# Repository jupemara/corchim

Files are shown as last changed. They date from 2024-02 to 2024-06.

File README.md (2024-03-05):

# corchim

Corchim ([Corne](https://github.com/foostan/crkbd/tree/main) by [foostan@](https://twitter.com/foostan) alminum gasket mount case) build guide

## 日本語はこちら

- Corne cherry v3
  - [PCB](./docs/ja/corne-cherry-v3.md)
  - [Corchim](./docs/ja/corchim-cherry-v3.md)

## English version

- Corne cherry v3
  - [PCB](./docs/en/corne-cherry-v3.md)
  - [Corchim](./docs/en/corchim-cherry-v3.md)

## switch plate data (.step and .dxf)

under the `data/switch-plate` dir

- corchim-switch-plate-{left,right}.{step,dxf}
  - normal corchim switch plate. If you need other material switch plates, please use those data.
- corchim-switch-plate-topre-{left,right}.{step,dxf}
  - for topre housing, 14.6 x 14
  - maybe for CorneECRevival, however I have not try strictly... TRRS connector position seems to be slightly changed compared with original corne v3.
- corchim-switch-plate-xiao-{left,right}.{step,dxf}
  - for xiao/rev2
  - maybe you can put batteries under the OLED. however nice!view is sold out in everywhere :innocent::innocent::innocent:

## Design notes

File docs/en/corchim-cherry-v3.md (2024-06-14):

# Corchim with Corne Cherry v3

## Procedures

### 1. Check the Contents

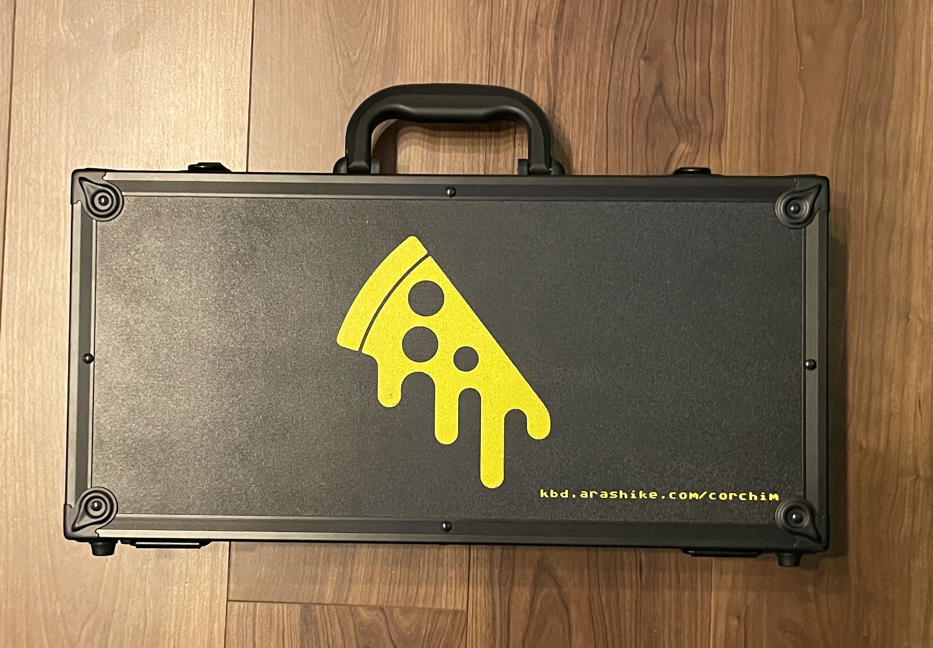
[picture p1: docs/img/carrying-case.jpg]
Open the carrying case


| Name | Quantity |
| --- | --- |
| Complete set for both left and right cases | 1 pair |
| Case foam (to be placed between the case and the PCB) | 2 pairs  |
| Switch foam (to be placed between the PCB and switch plate) | 1 pair |
| Switch plate (Polycarbonate) | 1 pair |
| Gasket (with adhesive) | 1 pair |
| Height adjustment foam for MCU | 1 pair |
| OLED pin socket with 5.7mm height | 2 pieces |
| OLED pin header with 1.5mm height | 2 pieces |
| Rubber Feet | 8 pieces |

Only BoB, different screws is used from the factory assembly, so screws are included separately.
Space Gray uses factory assembled screws.

| Name | Quantity |
| --- | --- |
| Screws for securing top and bottom of the case: Hex M2 x 8mm | 8 pieces (4 each for left and right) |
| Screws for securing weight: Hexalobular M3 x 4mm | 4 pieces (2 each for left and right) |

Each left and right case includes:

- left
  - Top body
  - Bottom body
  - Weight
  - PC plate
- right
  - Top body
  - Bottom body
  - Weight
  - PC plate

### 2. Remove the Case and Unscrew

Unscrew the temporarily fixed screws from the factory.

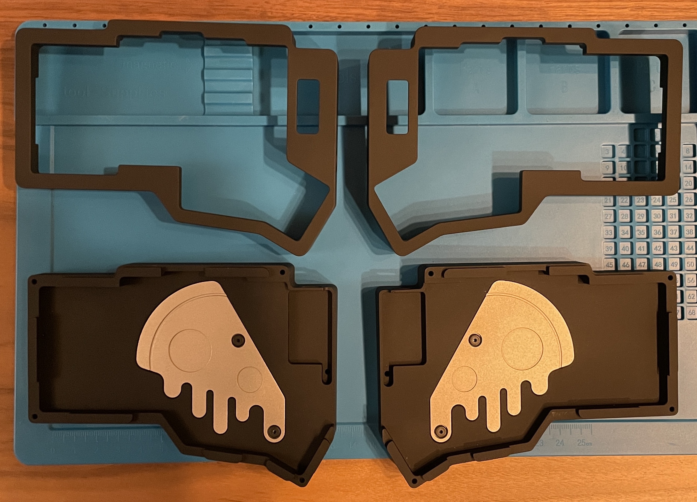
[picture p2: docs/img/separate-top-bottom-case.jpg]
Separating the case


#### Only BoB

Replace the weight screws with the provided black M3 x 4mm screws.
Space Gray is used as is from the factory, so there is no need to unscrew the weights.

#### Wrench

- For Space Gray
  - Hex wrench 1.27mm (0.05 inch)
- For BoB
  - removal: Hex wrench 1.5mm
  - installation: Hex wrench 1.25mm (0.05 inch) + T8 torx screwdriver (for weight)

### 3. Installing the Case Foam

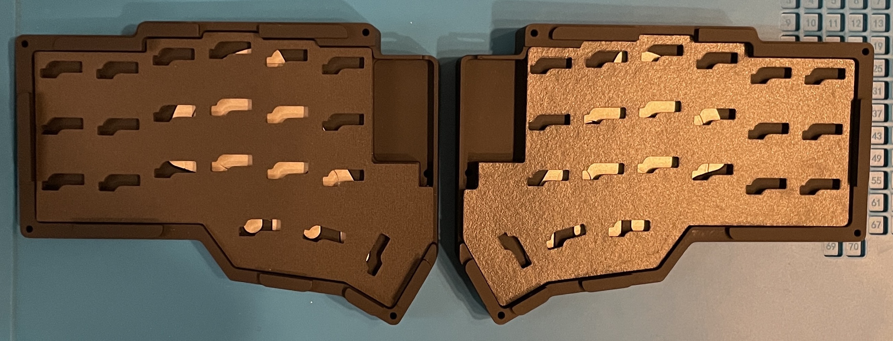
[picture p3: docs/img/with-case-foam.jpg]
Installing the case foam


#### 3-a. (optional) Installing the MCU Foam

While not necessary, this mitigates the mcu shifting around when unplugging and plugging in the USB-C port.
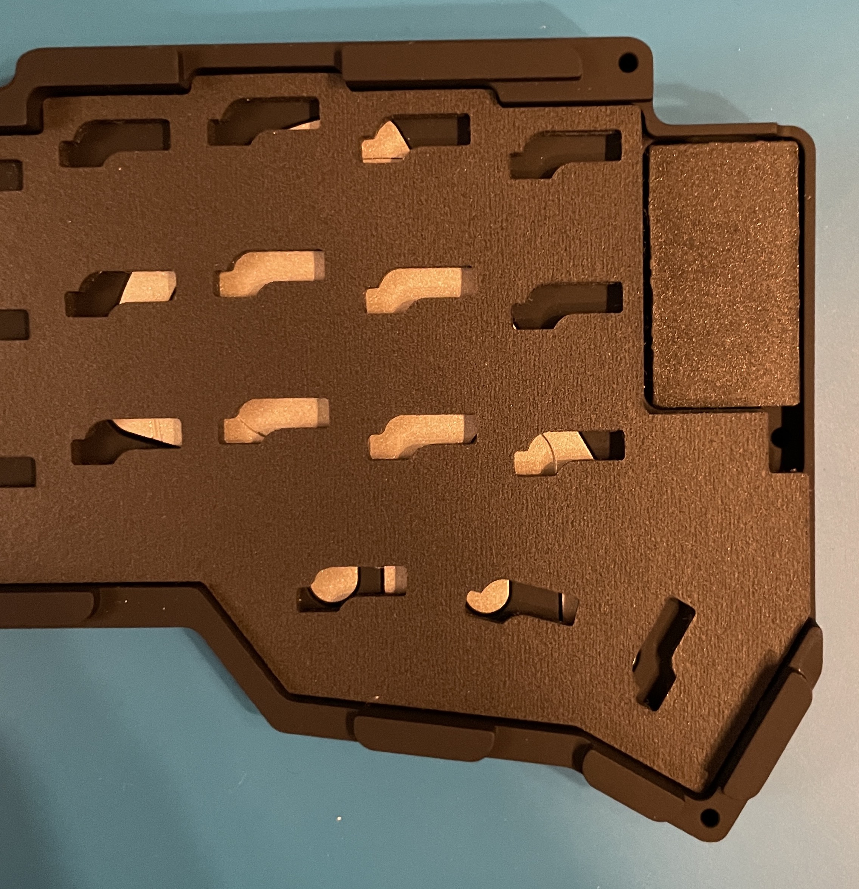
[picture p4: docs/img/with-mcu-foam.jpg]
with MCU foam


#### 3-b. (optional) When Installing a PCB with LEDs

If you already have LEDs installed, it's a single layer of case foam, otherwise the board will feel stiff.

### 4. Installing the PCB

Place the PCB on top of the case foam, ensuring it aligns with the socket holes in the foam.

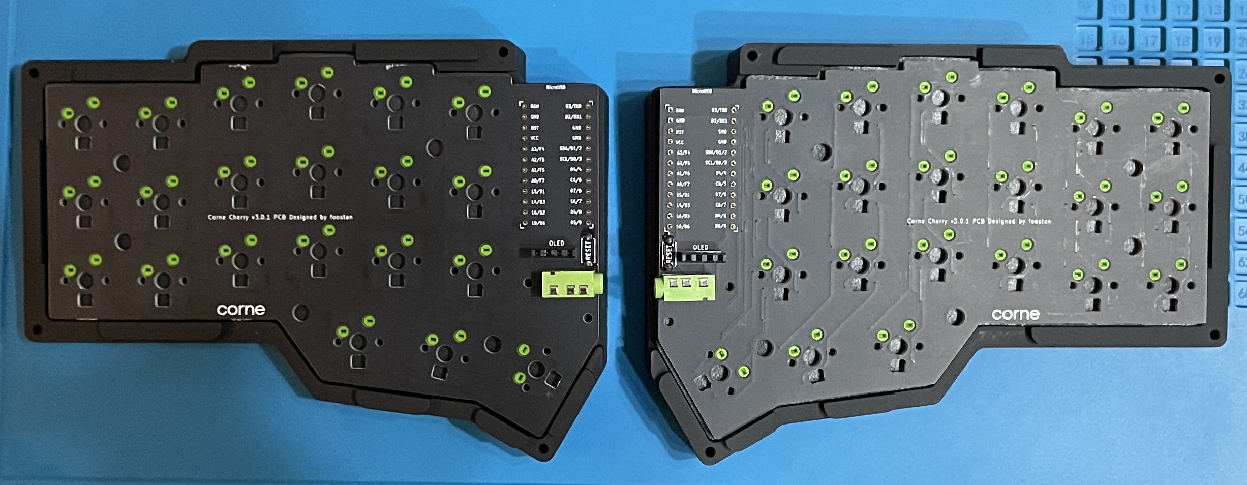
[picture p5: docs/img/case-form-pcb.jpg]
Installing the PCB


### 5. Gasket and OLED Supporting Foam

Attach the gasket to the switch plate.

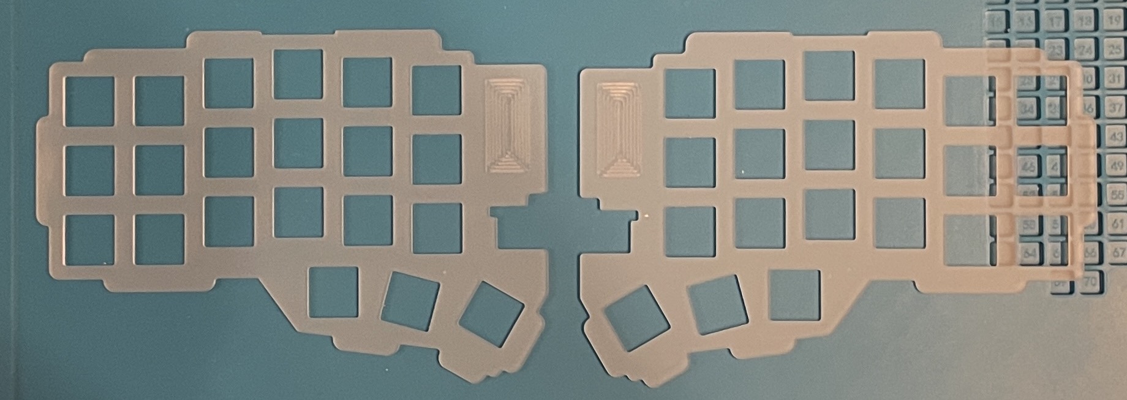
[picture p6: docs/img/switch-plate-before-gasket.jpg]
Switch plate before attaching gasket


At this time, also attach the OLED supporting foam to fit the OLED recess.

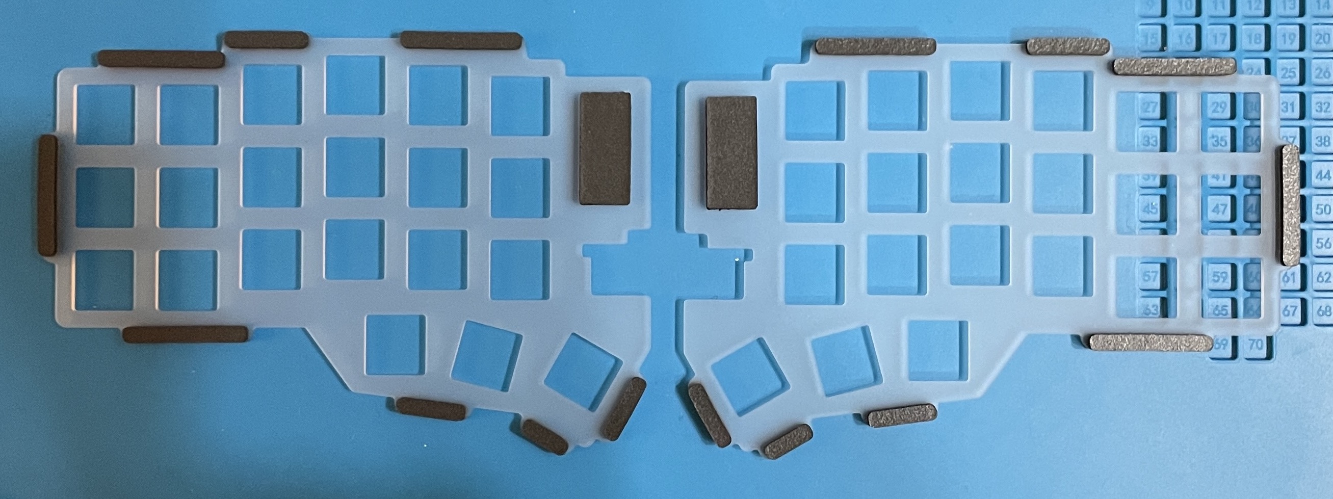
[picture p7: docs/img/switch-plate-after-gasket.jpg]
Switch plate after attaching gasket


The gasket comes in four lengths, so attach them to fit both sides (front and back).

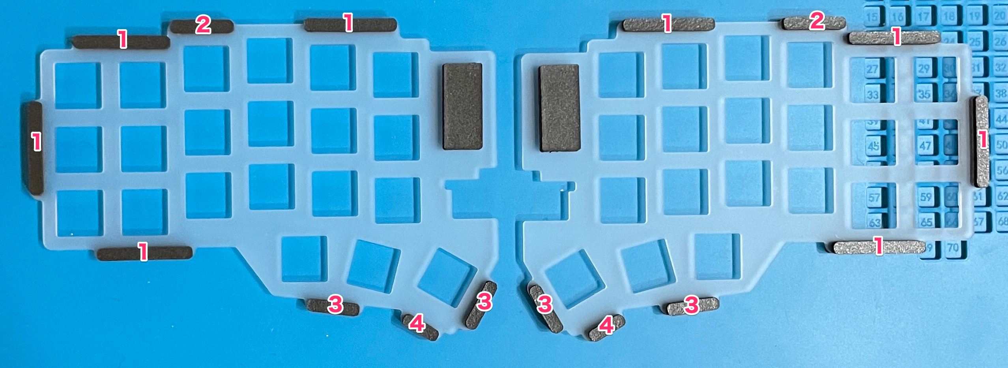
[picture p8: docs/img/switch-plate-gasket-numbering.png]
Numbering of gaskets on the switch foam side


### 6. Setting the Switch Plate and Switch Foam

Lay the switch foam on top of the PCB as shown in the picture.

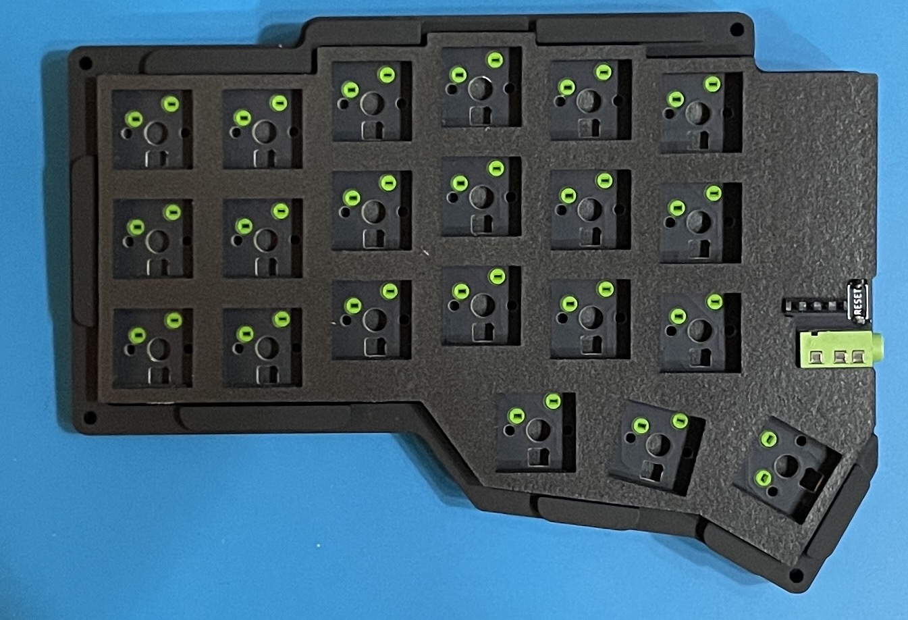
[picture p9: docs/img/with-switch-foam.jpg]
Laying the switch foam


Then, lay the switch plate on top. To prevent the switch plate and switch foam from shifting when covering the case, secure the four corners with appropriate key switches.
This is also a good time to add the OLED.

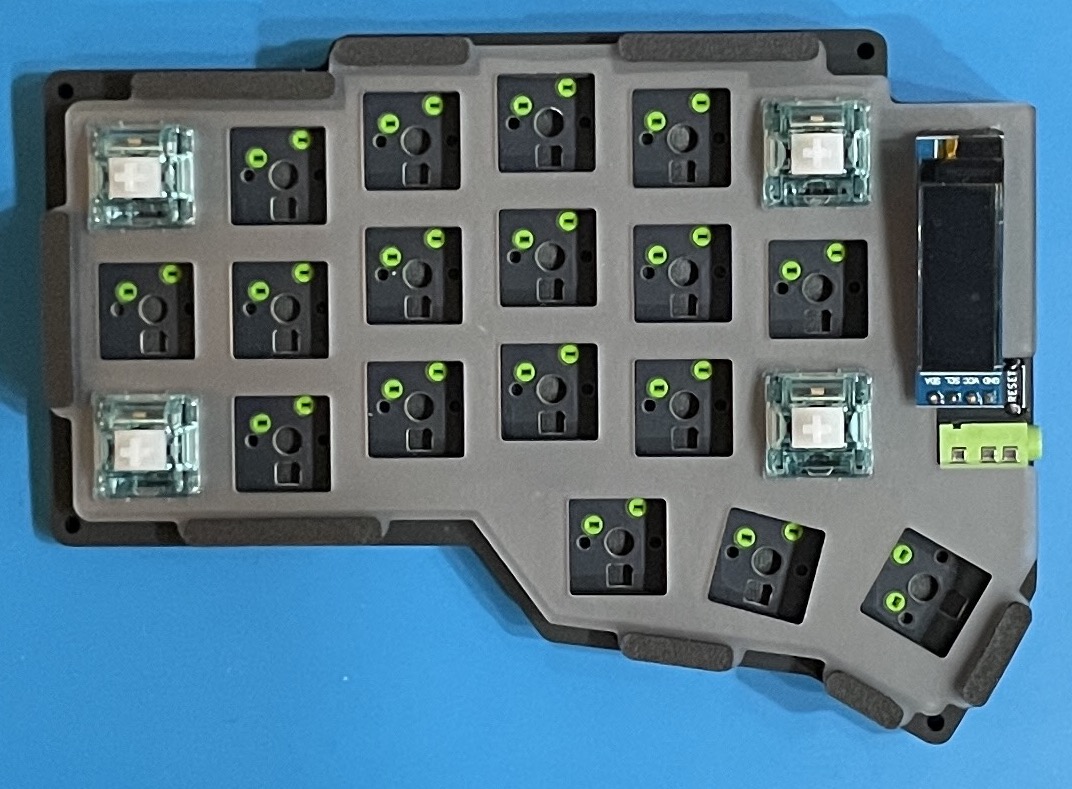
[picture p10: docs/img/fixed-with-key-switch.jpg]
Securing the foam and switch plate with key switches


### 7. Cover with Top Body and Screw Together

Cover with the top body and secure from the bottom with four M2 x 8mm screws.

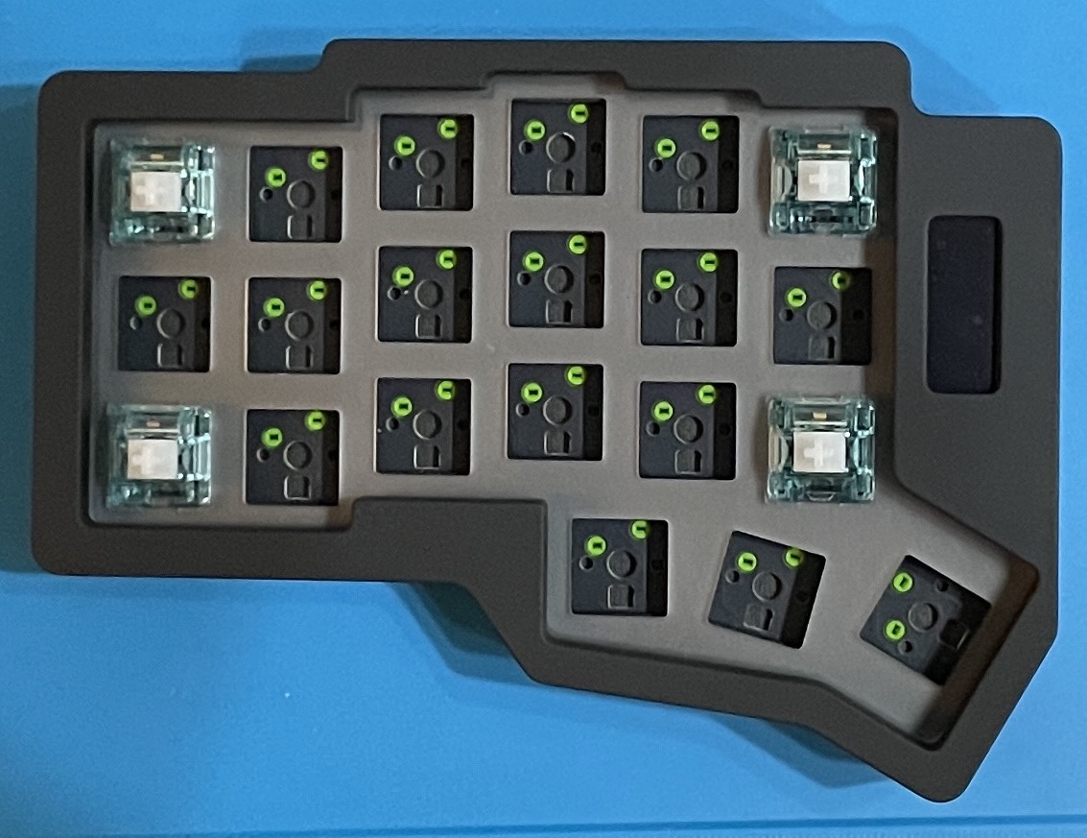
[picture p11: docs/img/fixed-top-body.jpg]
Securing the top and bottom


### 8. Rubber Feet

Attach the rubber feet to the holes on the bottom of the case.

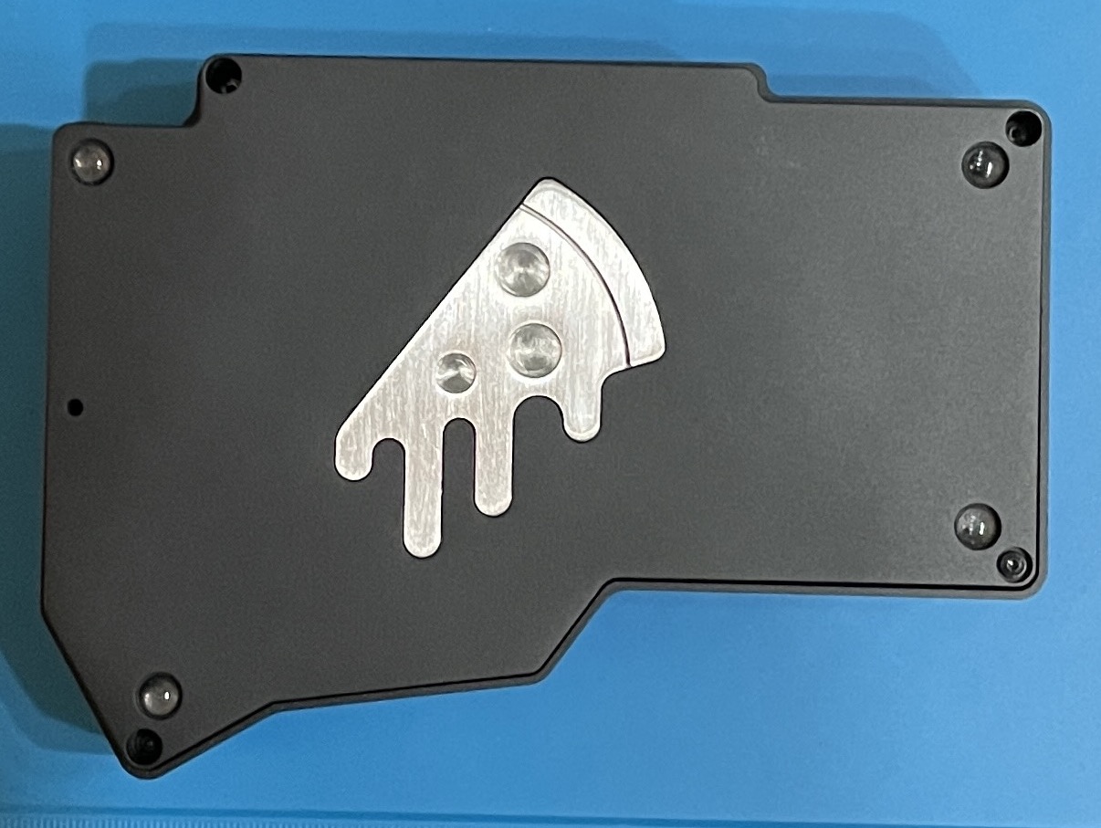
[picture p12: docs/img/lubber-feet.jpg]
Attaching rubber feet


### 9. Keycaps

Attach the keycaps, and it's complete!! Congrats!! Enjoy your Corchim!!

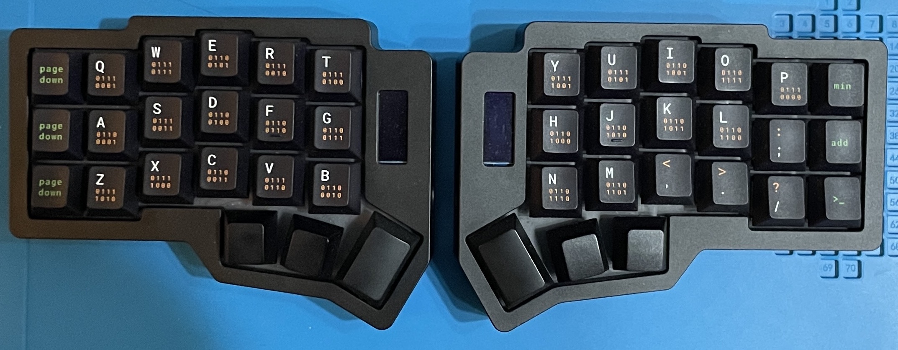
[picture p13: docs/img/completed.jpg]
Completed!!


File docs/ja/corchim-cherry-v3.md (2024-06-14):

# Corchim /w corne cherry v3

## 手順

### 1. 同梱物の確認

キャリングケースを開ける

| 名称 | 個数 |
| --- | ---- |
| ケース左右一式 | 1 対 |
| ケースフォーム (ケースと PCB の間に挟むもの) | 2 対 |
| スイッチフォーム (PCB とスイッチプレートの間に挟むもの) | 1 対 |
| スイッチプレート (ポリカーボネート) | 1 対 |
| ガスケット (粘着付き) | 1 対 |
| MCU 用高さ調整フォーム | 1 対 |
| OLED 高さ 5.7mm ピンソケット | 2 個 |
| OLED 高さ 1.5mm ピンヘッダ | 2 個 |
| ゴム足 | 8 個 |

BoB のみ工場組立とは異なるネジを使用するため、別途ネジが同梱されます。
Space Gray は工場組立のネジをそのまま利用します。

| 名称 | 個数 |
| --- | --- |
| ケース上下締結用ネジ: 六角 M2 x 8mm | 8 本 (左右 4 本ずつ) |
| ウェイト締結用ネジ: ヘクサロビュラ M3 x 4mm | 4 本 (左右 2 本ずつ) |

ケース左右には以下が含まれます

- left
  - トップ側ボディ
  - ボトム側ボディ
  - ウェイト
  - スイッチプレート
- right
  - トップ側ボディ
  - ボトム側ボディ
  - ウェイト
  - スイッチプレート

### 2. ケースを取り出し、ネジをはずす

工場製造時に仮止めしてあるネジがついているのでそちらのネジを外します。

ケースの分割

#### BoB のみ

ウェイトのネジを仮止め用のネジから付属の黒いネジ M3 x 4mm ネジと交換します。
Space Gray は工場組立時のそのまま利用するので、ウェイトのネジを外す必要はありません。

#### 使用するレンチ

- Space Gray
  - 六角レンチ 1.27mm (0.05 インチ)
- BoB
  - 取り外し: 六角レンチ 1.5mm
  - 取り付け: 六角レンチ 1.27mm (0.05 inch) + T8 トルクスドライバー (ウェイト用)

### 3. ケースフォームの設置

ケースフォームの設置

#### 3-a. (optional) MCU フォームの設置

通常必要ないはずですが、USB の抜き差しによって MCU が外れやすい場合は、こちらのフォームを敷いてください。
with MCU foam

#### 3-b. (optional) LED を実装した PCB を設置する際

アンダーグロー LED を実装済みの PCB を使用する際は、ケースフォームを 1 枚分の厚みだけで利用することを推奨します。
(2 枚の厚みでも問題なく動作しますが、ちょっと中身つまり過ぎな気がします)

### 4. PCB の設置

ケースフォームの上に PCB を設置します。このときケースフォームのソケットの位置に PCB が合うように設置します。

PCBの設置

### 5. ガスケットと OLED を支えるフォーム

スイッチプレートにガスケットを貼ります。

ガスケットを貼る前のスイッチプレート

このとき、OLED 用のくぼみに合うように OLED 用フォームも貼ります。

ガスケットを貼った後のスイッチプレート

ガスケットには長さが 4 種類あるのでサイズが合うように表面/裏面の両方に貼ります。

スイッチフォーム側のガスケットのナンバリング

### 6. スイッチプレートとスイッチフォームの設定

写真のようにスイッチフォームを PCB の上に敷きます。

スイッチフォームを敷く

さらにその上にスイッチプレートを敷きます。ケースを被せるときにスイッチプレートとスイッチフォームがずれるのを防ぐために適当なキースイッチで四隅を固定します。

キースイッチでフォームとスイッチプレートを固定する

### 7. トップボディをかぶせてネジで締結

トップボディをかぶせて、底側から M2 x 8mm のネジ 4 本で締結します。

上下の締結

### 8. ゴム足

ケース底面の穴にゴム足を取り付けます。

ゴム足の取り付け

### 9. キーキャップ

キーキャップを取り付けて完成!! Congrats!! Corchim をお楽しみください!!

完成!!

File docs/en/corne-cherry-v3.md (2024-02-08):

# Preparation for Corne Cherry v3 PCB

## Items Needed for PCB Assembly

| Name | Quantity |
| --- | --- |
| Corne Cherry v3 PCB | 1 set (left and right) |
| Surface mount diodes (1N4148W) | 42 |
| PCB sockets for MX | 42 |
| TRRS jack (PJ-320A) | 2 |
| OLED 128x32 | 2 |
| Compatible MCU | 2 |
| MCU conthrough(spring pin headers) or pin socket (height 2.5mm) | 4 |
| Tactile switches for reset (2 pin) | 2 |

---

The following items are necessary but included with Corchim:

| Name | Quantity |
| --- | --- |
| Pin sockets for OLED | 2 |
| Pin headers for OLED | 2 |

### A Note About the Color of Kailh MX Sockets

Since I was asked about this, the color doesn't matter; it's just fashion (although you might not see it with the case on). Places to purchase include:

- [Daily Craft Shop](https://shop.dailycraft.jp/products/keyswitch_socket_transparent)
- [Chosfox](https://chosfox.com/products/kailh-colorful-hot-swap-socket)
- [AliExpress](https://ja.aliexpress.com/item/1005003174680450.html)

### Compatible MCUs

- Elite-C
- Elite-Pi
- key micro
- Sea-Picro

For the key micro and Sea-Picro, we have confirmed that they operate without soldering on the MCU side. However, using Sea-Picro without soldering is not recommended due to its tendency to detach easily.

### About MCU conthrough

Due to the USB-C port, we recommend a height of 2.5mm.

## Assembly Steps

### 1. Soldering Diodes and Sockets

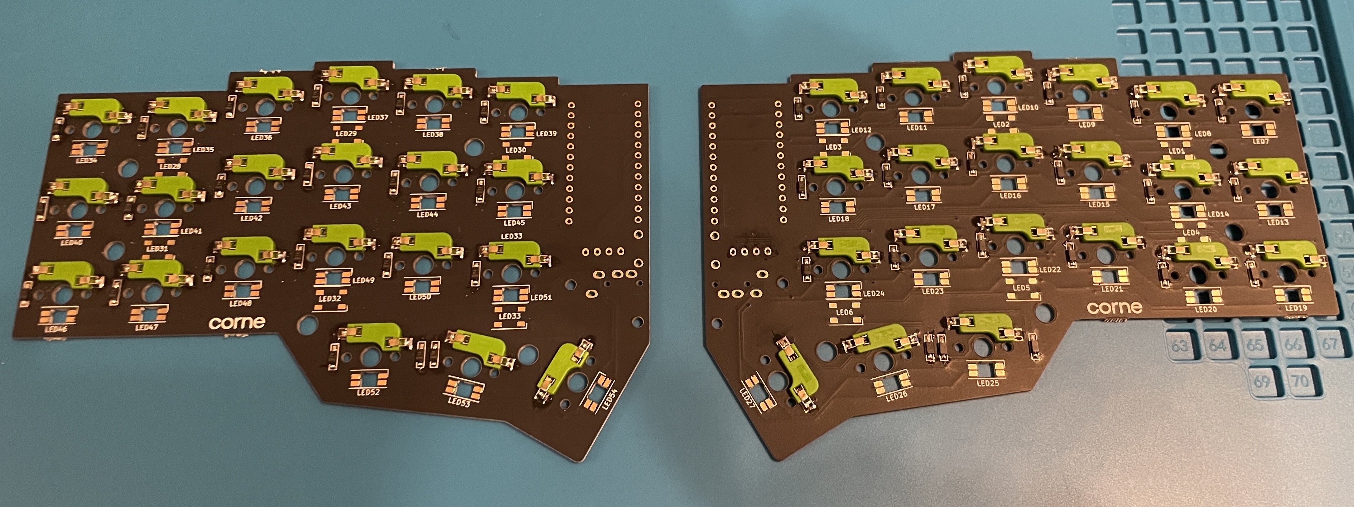
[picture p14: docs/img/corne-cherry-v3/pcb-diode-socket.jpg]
Soldering Diodes and Sockets


The soldering of [diodes](https://github.com/foostan/crkbd/blob/main/corne-cherry/doc/v3/buildguide_en.md#diodes) and [sockets](https://github.com/foostan/crkbd/blob/main/corne-cherry/doc/v3/buildguide_en.md#switch-sockets) follows the same steps as the [original Corne](https://github.com/foostan/crkbd/blob/main/corne-cherry/doc/v3/buildguide_en.md). LEDs are not supported, but having them is not a problem (more on this later).

### 2. Soldering the TRRS

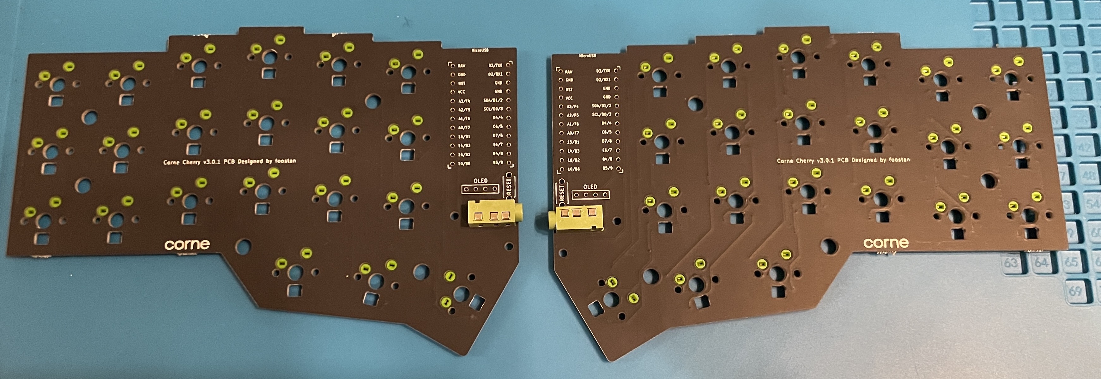
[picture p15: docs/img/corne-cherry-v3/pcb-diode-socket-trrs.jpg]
Soldering the TRRS


The TRRS jack is also soldered following the same procedure as the original Corne.

### 3. Soldering OLED Pin Sockets

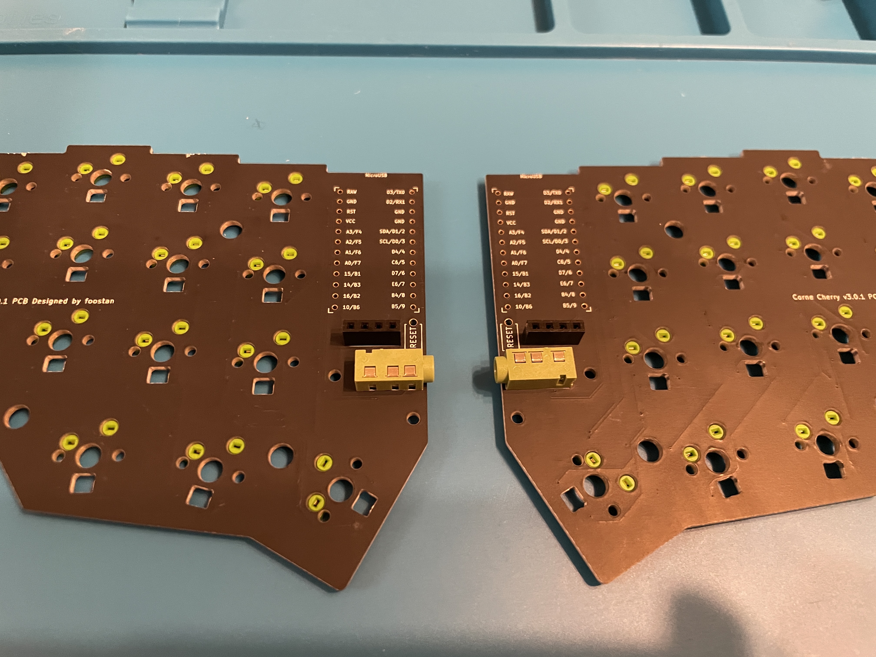
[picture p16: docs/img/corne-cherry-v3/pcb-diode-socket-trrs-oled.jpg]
Soldering OLED 5.7mm Pin Sockets


We include 5.7mm pin sockets and 1.5mm pin headers. However, the original 3.5mm pin sockets are also fine to use. Below are comparison images (there isn't much difference once the case is on).

3.5mm pin socket with 2.5mm pin header

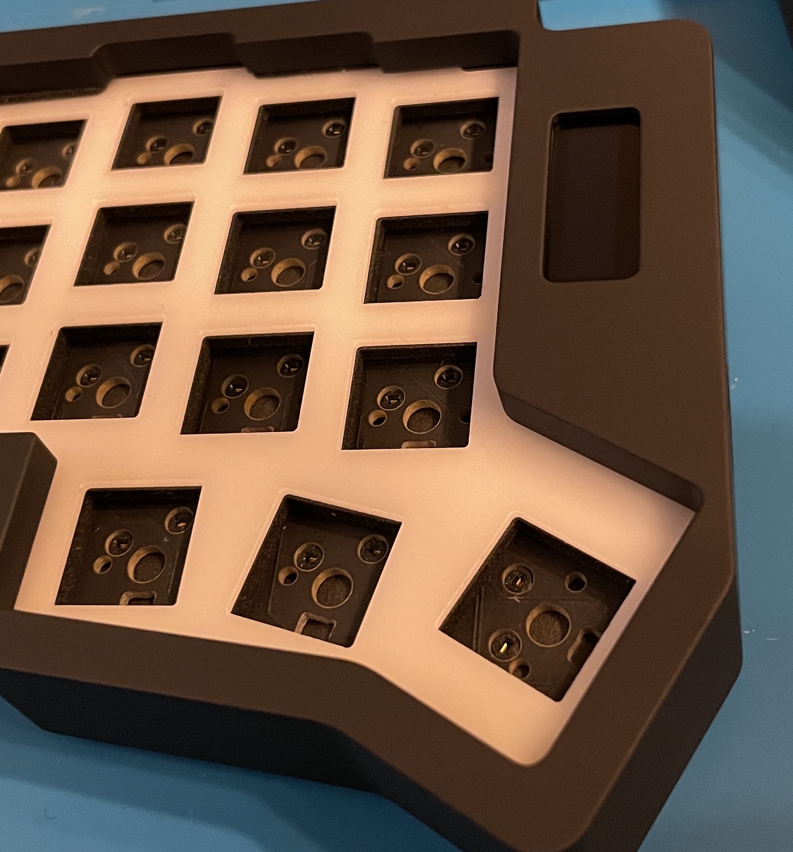
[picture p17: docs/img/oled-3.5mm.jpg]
3.5mm Pin Socket + Corchim


5.7mm pin socket with 1.5mm pin header

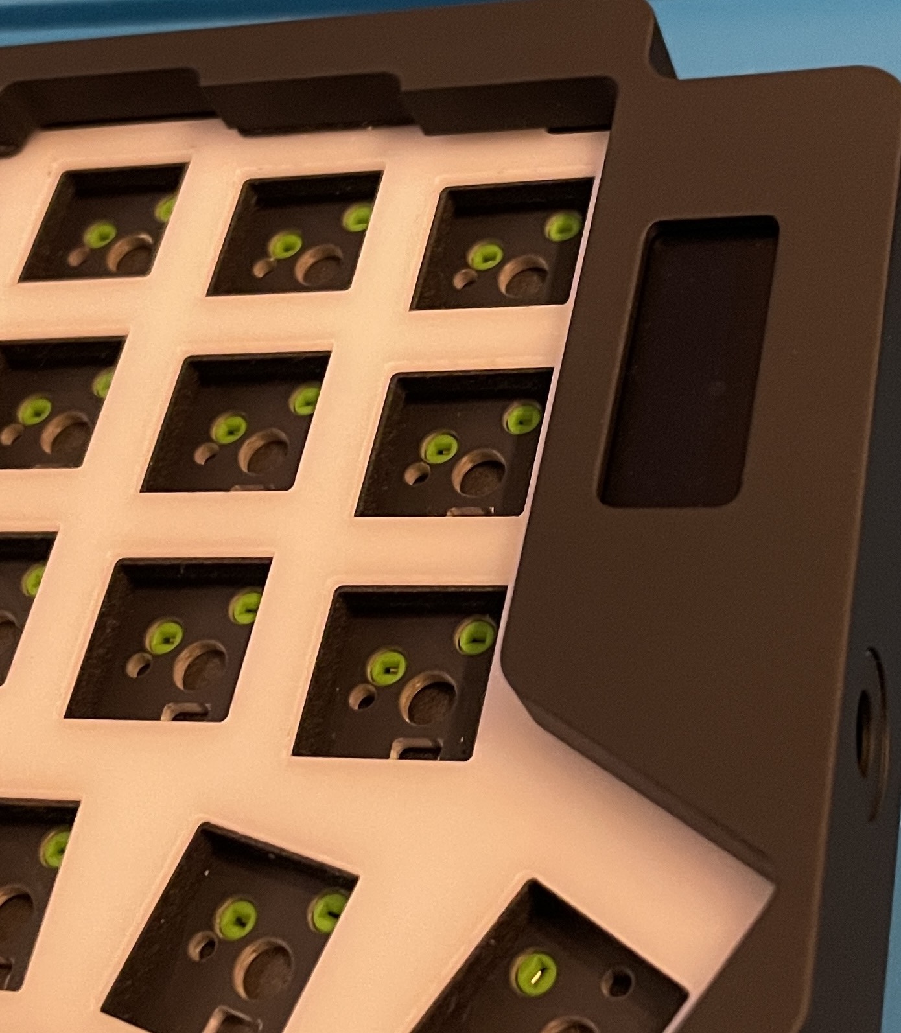
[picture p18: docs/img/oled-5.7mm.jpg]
5.7mm Pin Socket + Corchim


Please cut the ends of the pin headers with clippers after soldering them to the OLED.

### 4. Reset Switch (optional)

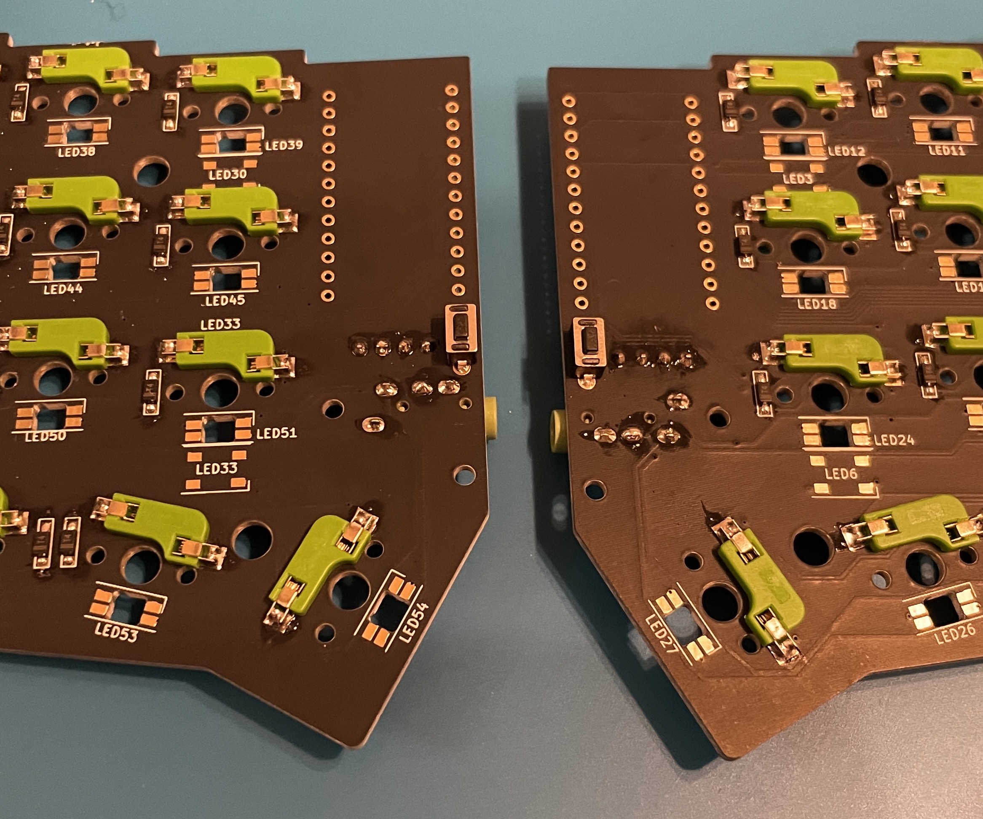
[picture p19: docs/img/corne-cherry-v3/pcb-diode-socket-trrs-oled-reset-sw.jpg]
Mounting the Reset Switch in Reverse


Mounting the reset switch on the opposite side (bottom of the PCB) compared to the original Corne allows for easier access to the reset switch from the bottom of the Corchim. (However, this is optional as it can be adjusted as needed.)

### 5. Mounting the MCU

Pay attention to the direction of the MCU as it differs from the original Corne. The MCU protrudes from the bottom of the PCB, as shown in the images. If you're unsure about the mounting direction, you can check by posting a photo on our [

discord](https://discord.gg/tuykB7h5d9).

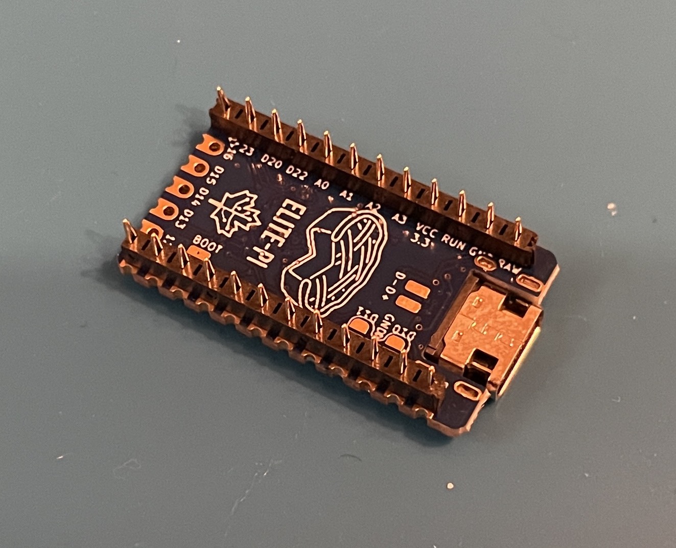
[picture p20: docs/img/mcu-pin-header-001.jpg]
MCU Pin Header 001

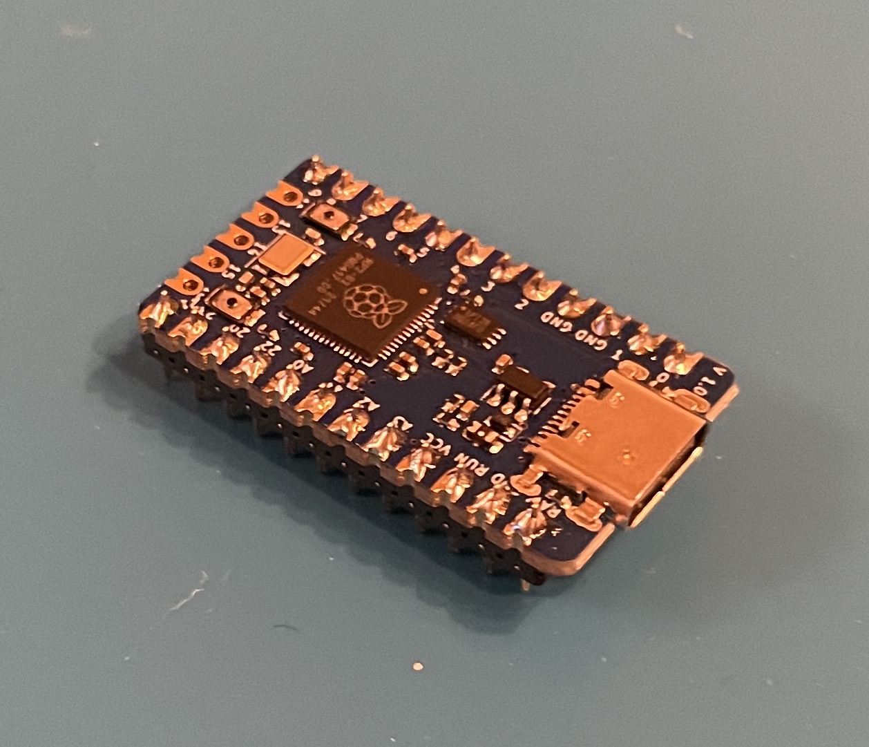
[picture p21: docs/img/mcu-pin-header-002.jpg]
MCU Pin Header 002

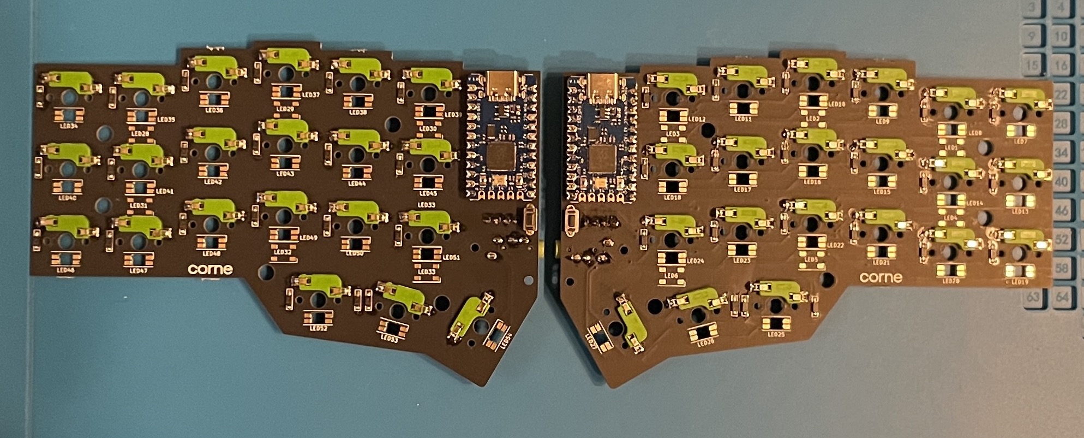
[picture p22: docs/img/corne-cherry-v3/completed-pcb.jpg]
Completed PCB with MCU Mounted


This completes the PCB assembly. Well done! Next, let's attach it to the case! [Case Assembly Guide](./corchim-cherry-v3.md)

## Firmware

I've tested with QMK version 0.23.7. I'm using crkbd/rev1, keymaps/default without any changes.

### Elite-C

```sh
$ make crkbd:default:dfu
```

Ref: [QMK Flashing Guide](https://github.com/qmk/qmk_firmware/blob/master/docs/flashing.md#make-targets)

### Elite-Pi

```sh
$ qmk flash -c -kb crkbd/rev1 -km default -e CONVERT_TO=elite_pi
```

Ref: [Keeb.io Elite-Pi Guide](https://docs.keeb.io/elite-pi-guide)

### key micro

```sh
$ make crkbd:default:dfu
```

Ref: [Abitkeys Key Micro Build Guide](https://abitkeys.com/keymicro/build.html)

### Sea-Picro

```sh
$ qmk flash -c -kb crkbd/rev1 -km default -e CONVERT_TO=promicro_rp2040
```

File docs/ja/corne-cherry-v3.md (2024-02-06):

# PCB 準備 for Corne cherry v3

## PCB 組み立てに必要なもの

| 名称 | 個数 |
| --- | --- |
| Corne cherry v3 PCB | 1 セット (左右分) |
| 表面実装ダイオード ( 1N4148W ) | 42 個 |
| MX 用 PCB ソケット | 42 個 |
| TRRS ジャック ( PJ-320A ) | 2 個 |
| OLED 128x32 | 2 個 |
| 対応してる MCU | 2 個 |
| MCU 用コンスルーピンまたはピンソケット (高さ 2.5mm) | 4 個 |
| リセットスイッチ用タクトスイッチ (2 ピン ) | 2 個 |

---

以下は必要ですが, Corchim に同梱されています

| 名称 | 個数 |
| --- | ---- |
| OLED 用ピンソケット | 2 個 |
| OLED 用ピンヘッダ | 2 個 |

### 余談 kailh MX 用ソケットの色について

某所で質問されたので答えておくと、色はなんでも問題ありません。ファッションです ( ケースつけると見えないので特に意味はないかもですけど )。購入先としては

- https://shop.dailycraft.jp/products/keyswitch_socket_transparent
- https://chosfox.com/products/kailh-colorful-hot-swap-socket
- https://ja.aliexpress.com/item/1005003174680450.html

このあたりです。

### compatible MCU

- Elite-C
- Elite-Pi
- key micro
- Sea-Picro

上記のうち, key micro と Sea-Picro に関しては MCU 側のはんだ付けなしで動作することを確認しています。
ただし Sea-Picro をはんだなしで利用するのはかなり抜けやすいのであまりおすすめしません。

### MCU 用のピンソケット (コンスルーピン) について

USB-C の差込口の関係で, 高さ 2.5mm を推奨としいます。

## 手順

### 1. ダイオードとソケットのはんだ付け

ダイオードとソケットのはんだ付け

[ダイオード](https://github.com/foostan/crkbd/blob/main/corne-cherry/doc/v3/buildguide_jp.md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)と[ソケット](https://github.com/foostan/crkbd/blob/main/corne-cherry/doc/v3/buildguide_jp.md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)のはんだ付けは[オリジナルの Corne](https://github.com/foostan/crkbd/blob/main/corne-cherry/doc/v3/buildguide_jp.md)と手同じ手順です。
LED は not supported です。っが、ついていても特に問題ありません (後述します) 。

### 2. TRRS のはんだ付け

TRRSのはんだ付け

TRRS も同様にオリジナルの Corne と同じ手順です。

### 3. OLED ピンソケットのはんだ付け

OLED5.7mmピンソケットのはんだ付け

5.7mm のピンソケットと 1.5mm のピンヘッダを同梱しています。
ですが、オリジナルに同梱されている 3.5mm のピンソケットであっても特に問題ないので、どちらを使っていただいても問題ありません。以下は比較画像 (ケースをかぶせるとどちらも大きく違いはありません)

3.5mm ピンソケットに 2.5mm ピンヘッダ

3.5mmピンソケット+corchim

5.7mm ピンソケットに 1.5mm ピンヘッダ

5.7mmピンソケット+corchim

OLED 側のピンヘッダははんだ付け後、ピンの先をニッパー等でカットしてください。

### 4. リセットスイッチ (optional)

リセットスイッチを逆向きにつける

オリジナル Corne とは反対向きに (基盤の底側に) リセットスイッチをつけることで Corchim 底側からリセットスイッチを押せるようになります。( ただこちらはなんとでもなると思うので、optional 扱いです )

### 5. MCU 取り付け

MCU の取り付け方向がオリジナルの Corne とは違うので注意です。基盤の底面から MCU が生えてくる形になるので、画像のような取付方向となります。(もし取付方向に不安が残る場合は [discord](https://discord.gg/tuykB7h5d9) に写真を貼っていただければ確認します)

MCUピンヘッダ001
MCUピンヘッダ002
MCU取り付け済み PCB

ここまでで一旦 PCB は完成です, お疲れ様です!! ケースに取り付けていきましょう!! [ケース編](./corchim-cherry-v3.md)

## ファームウェア

QMK バージョン は 0.23.7 で試してます。0.23.7 における crkbd/rev1 , keymaps/default を変更無しで使用しています。

### Elite-C

```sh
$ make crkbd:default:dfu
```

ref: https://github.com/qmk/qmk_firmware/blob/master/docs/flashing.md#make-targets

### Elite-Pi

```sh
$ qmk flash -c -kb crkbd/rev1 -km default -e CONVERT_TO=elite_pi
```

ref: https://docs.keeb.io/elite-pi-guide

### key micro

```sh
$ make crkbd:default:dfu
```

ref: https://abitkeys.com/keymicro/build.html

### Sea-Picro

```sh
$ qmk flash -c -kb crkbd/rev1 -km default -e CONVERT_TO=promicro_rp2040
```

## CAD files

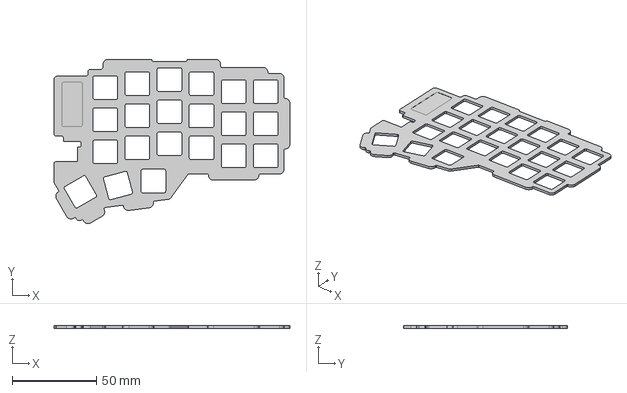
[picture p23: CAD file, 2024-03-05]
data/switch-plate/corchim-switch-plate-topre-right.step
139.7 x 97.2 x 1.50 mm

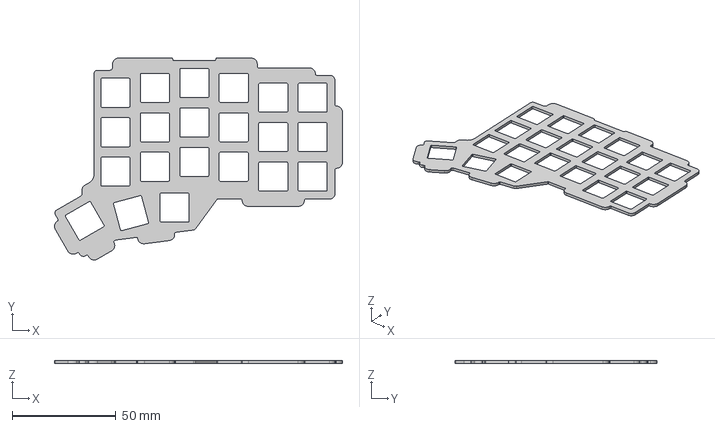
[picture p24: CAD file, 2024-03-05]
data/switch-plate/corchim-switch-plate-xiao-right.step
138.7 x 97.2 x 1.50 mm

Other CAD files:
data/switch-plate/corchim-switch-plate-left.step
data/switch-plate/corchim-switch-plate-topre-left.step
data/switch-plate/corchim-switch-plate-right.step
data/switch-plate/corchim-switch-plate-xiao-left.step
data/switch-plate/corchim-switch-plate-left.dxf
data/switch-plate/corchim-switch-plate-right.dxf
data/switch-plate/corchim-switch-plate-topre-left.dxf
data/switch-plate/corchim-switch-plate-topre-right.dxf
data/switch-plate/corchim-switch-plate-xiao-left.dxf
data/switch-plate/corchim-switch-plate-xiao-right.dxf

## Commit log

2024-02-05 ja: corchim case build guide
2024-02-05 link to corchim and pcb docs link
2024-02-05 with LED PCB
2024-02-05 about sea-picro soldering
2024-02-14 switch plate => PC Plate
2024-03-05 all switch plate data
    [corchim-switch-plate-left.dxf, corchim-switch-plate-left.step, corchim-switch-plate-right.dxf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]
2024-03-05 about switch-plate data
2024-04-27 about space-gray screws
